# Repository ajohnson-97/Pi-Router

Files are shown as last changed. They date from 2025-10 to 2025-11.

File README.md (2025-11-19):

# Pi-Router

Custom-built dual 2.5Gb ethernet and WIFI 6e router/dns-sinkhole using Raspberry Pi SBCs and a custom ATMEGA328P-PU circuit for a toggle switch controlled password system to display system configuration details on the LCD screens and control two servo motors that lock/unlock the enclosure.<br><br>
## License

- The code in this repository is licensed under the [MIT License](./LICENSE).
- All images, logos, and branding assets are licensed under the [CC BY-NC-ND 4.0 License](https://creativecommons.org/licenses/by-nc-nd/4.0/). <br>
- See [ASSETS_LICENSE.txt](./ASSETS_LICENSE.txt) for details.
<br><br>
pirouter_Logo (Copy).png
<br><br>
<!--
# Licensing
The code in this repository is licensed under the MIT License. <br> 
- Feel free to use the code in your project or modify/redistribute it any way you'd like.<br>

However, all images, branding, and logo assets (found in the /assets directory) may not be used for commercial purposes or in other projects without explicit permission.
-->


<br><br>

<br><br>

<br><br>

<br><br>

<br><br>

<br><br>

<br><br>
Wiring_Diagram_TinkerCAD
<br><br>

<br><br>


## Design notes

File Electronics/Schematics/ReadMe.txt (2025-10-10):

The schematic and wiring diagram feature an Arduino Uno because I designed the prototype using tinkerCAD and it doesn't have an object for the atmega328p-pu chip that I used in the actual project. You can get away with using any Arduino as it uses the same chip, assuming you can accommodate the space and adjust the mounting holes accordingly. If you want to use the atmega chip directly like I did you'll have to research how to do it yourself for the most part, but basically, it's the same connections as the Arduino. You'll need to consult a pinout diagram to make sure you're connecting wires from the digital output pin numbers and not by counting the hardware pins on the chip. For example the first pin on the chip is the reset pin, not digital output pin 1, consult the diagram and you'll understand what I mean. You'll also want to solder a 16Mhz crystal oscillator to the corresponding pins and connect them to ground through 100pF ceramic capacitors. I also added a 10kohm resistor from the reset pin to VCC as a pullup resistor to reset the chip, you can skip this step if you set the pinMode using the built-in pullup resistor in your code. I also put a 100uF polarized capacitor across 5V and ground to smooth out any electrical noise, it's not necessary but recommended.

The schematics might not be fully accurate, they were generated from tinkercad and I changed up the final design a bit in my project. It's more for reference.

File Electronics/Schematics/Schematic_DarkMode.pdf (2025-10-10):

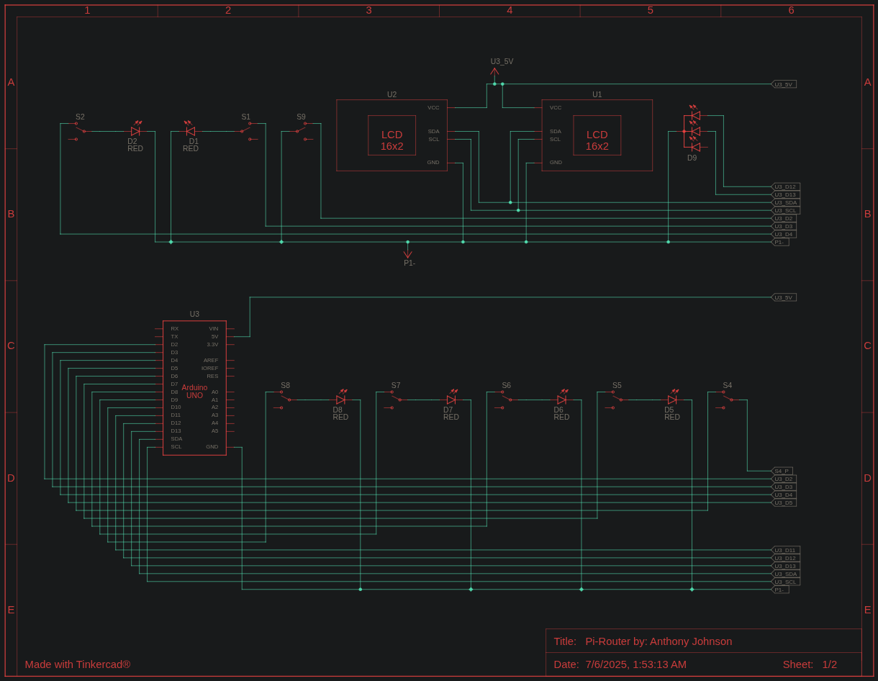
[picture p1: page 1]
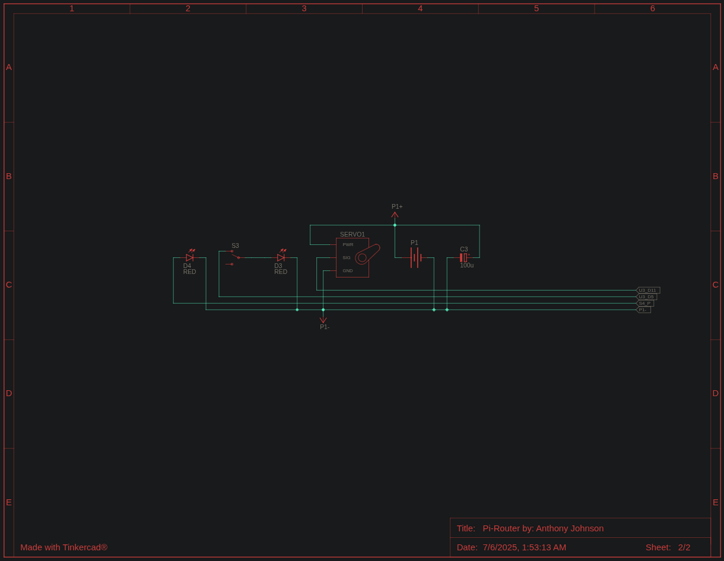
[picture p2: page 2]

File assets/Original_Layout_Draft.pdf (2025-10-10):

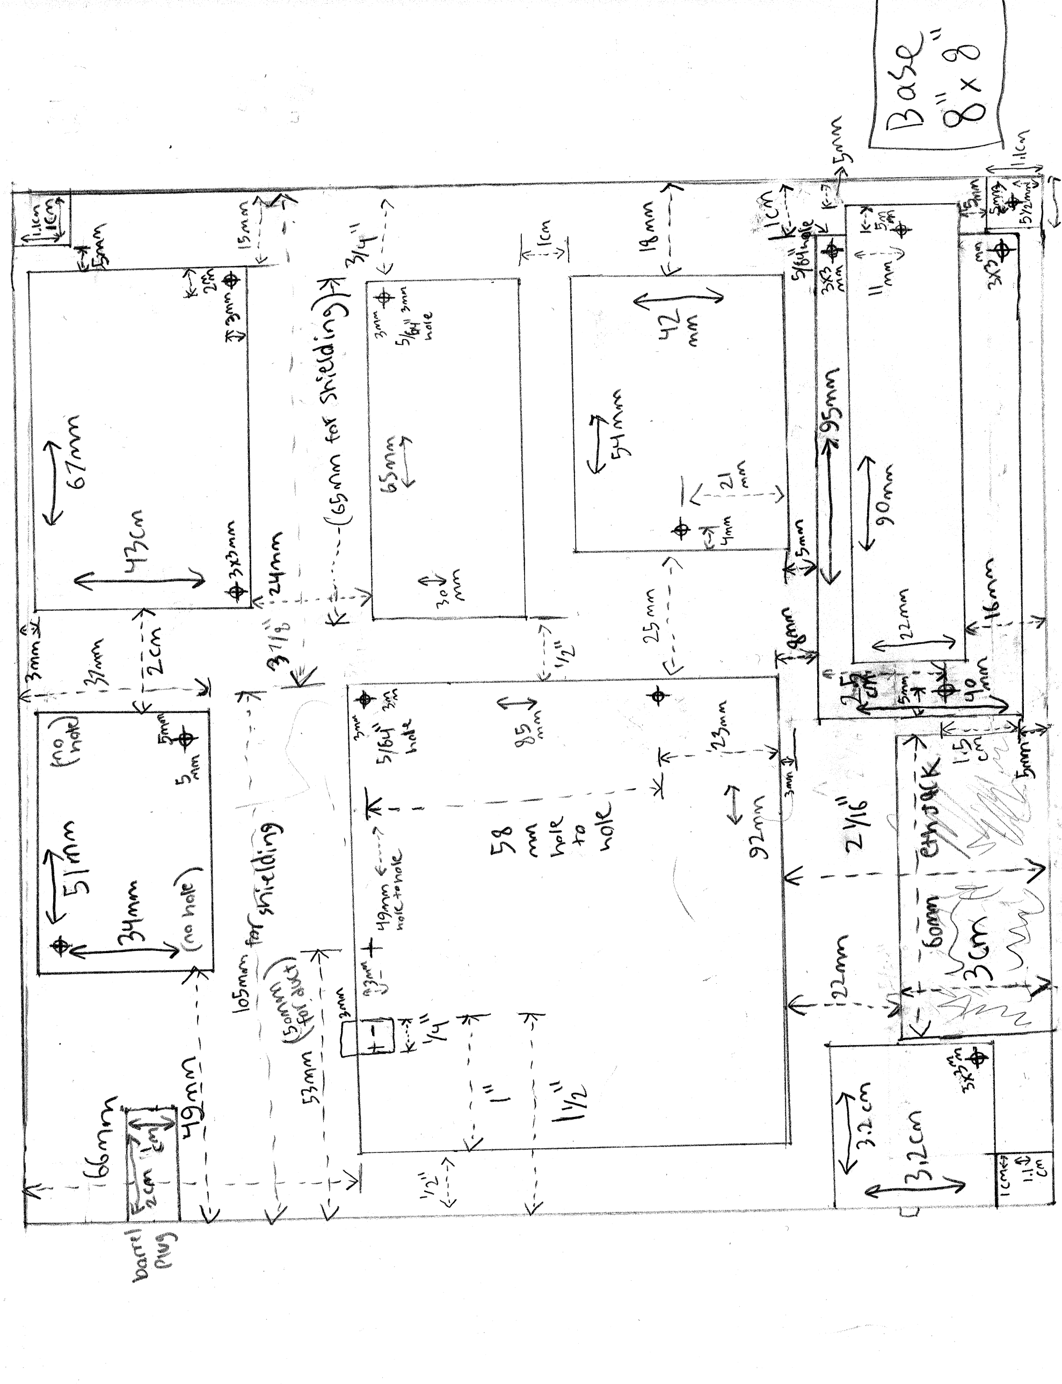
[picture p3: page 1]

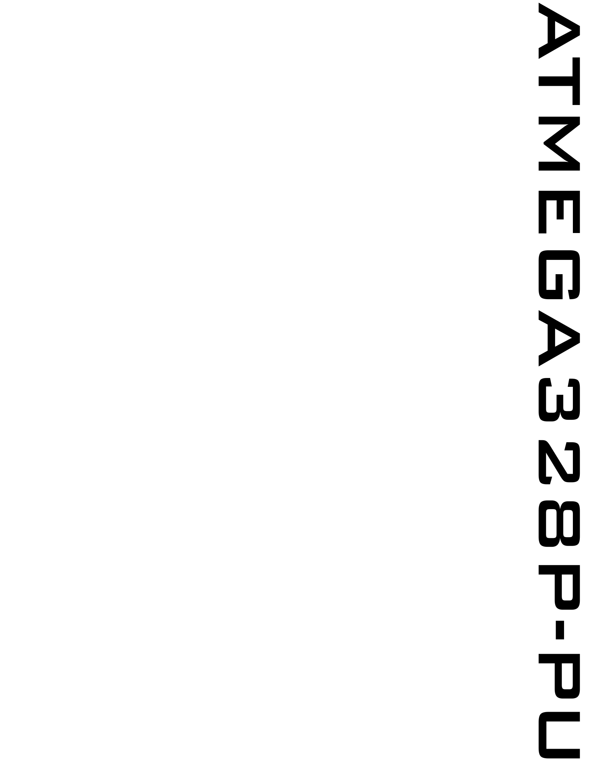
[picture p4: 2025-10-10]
CAD Files/PNGs/atmega328.png

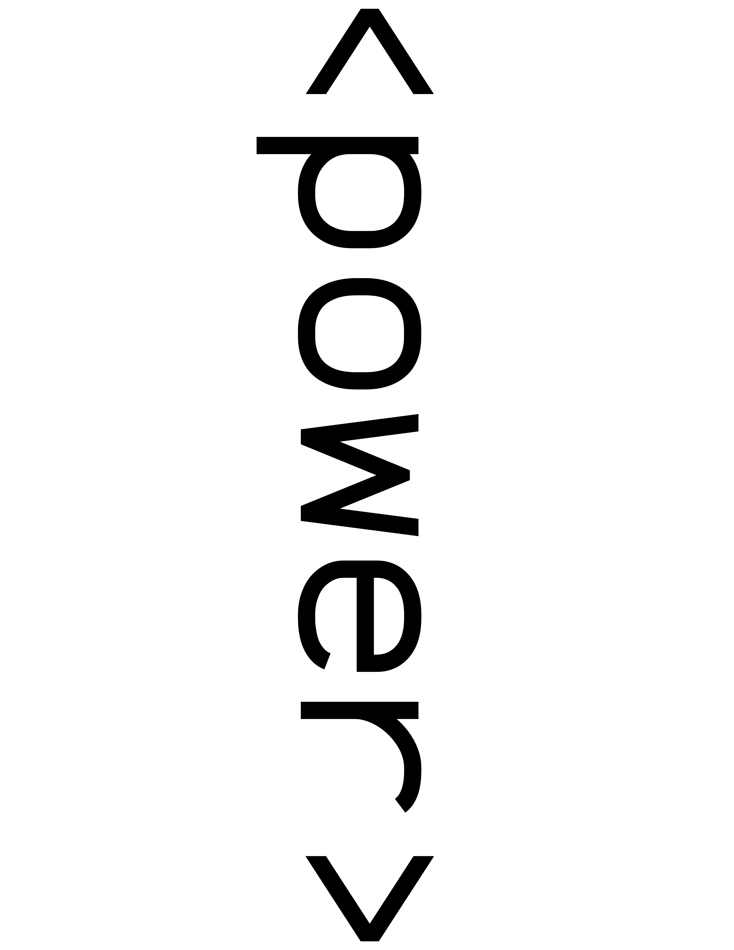
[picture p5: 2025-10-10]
CAD Files/PNGs/power.png

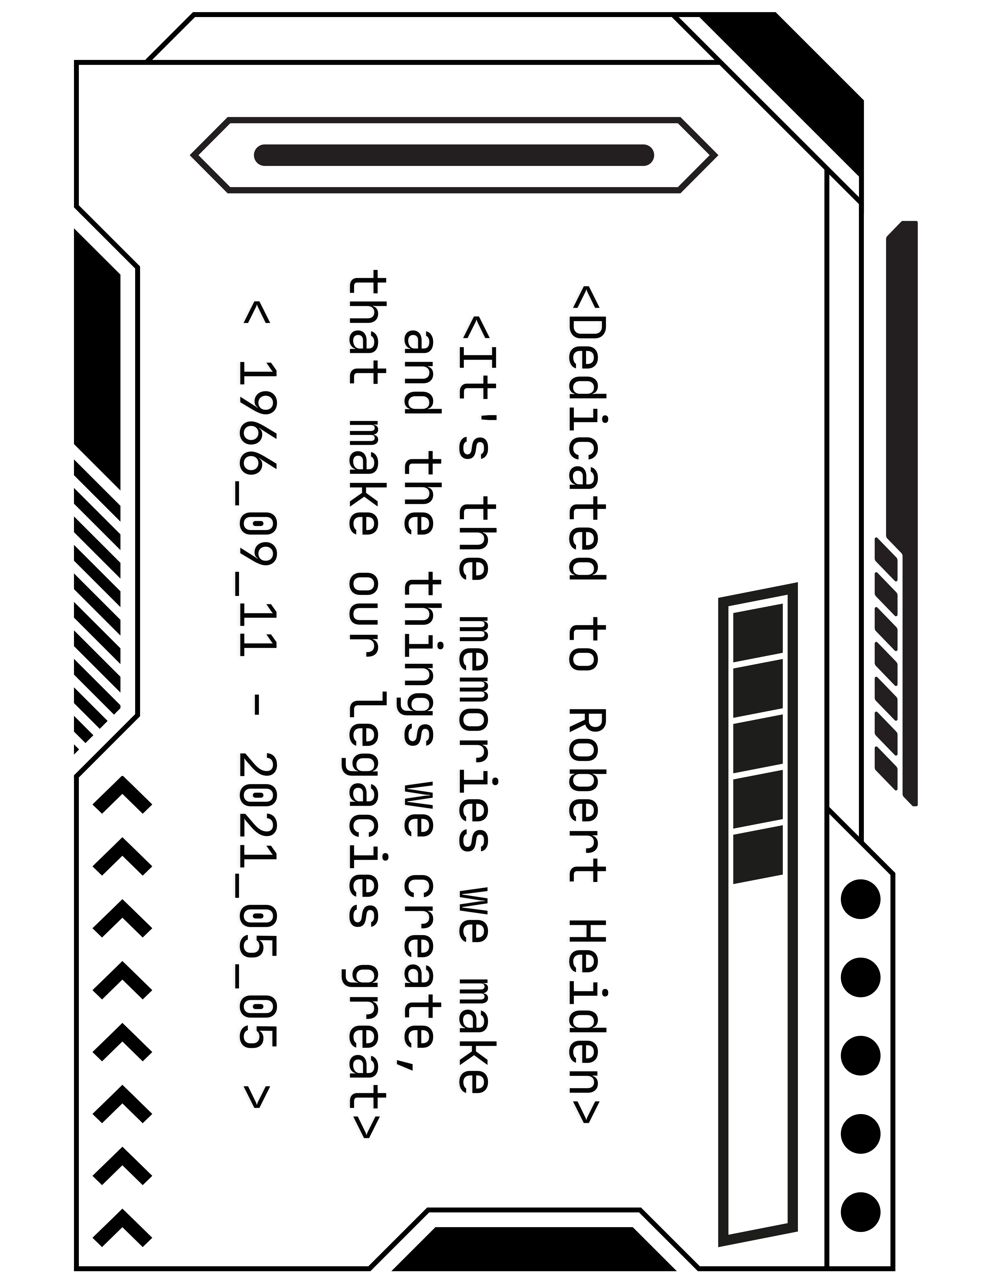
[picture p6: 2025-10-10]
CAD Files/PNGs/dedication.png

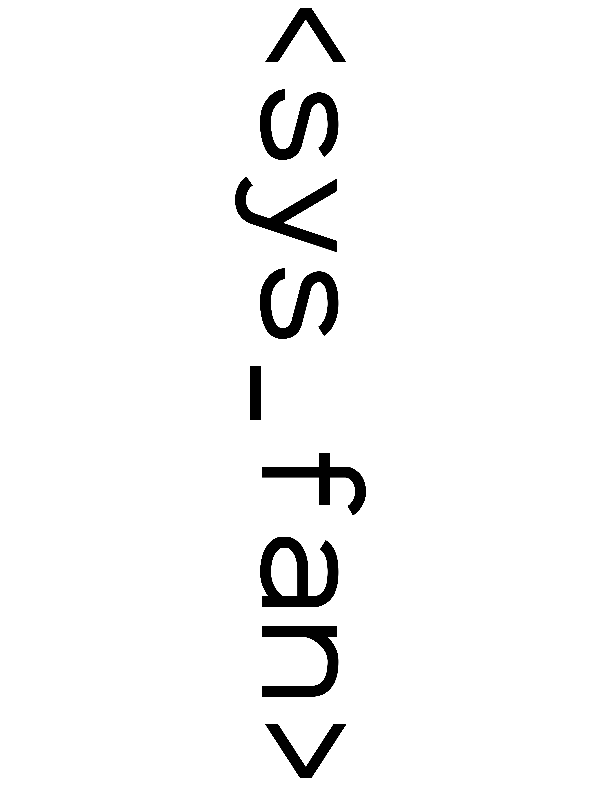
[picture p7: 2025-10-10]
CAD Files/PNGs/sysfan.png

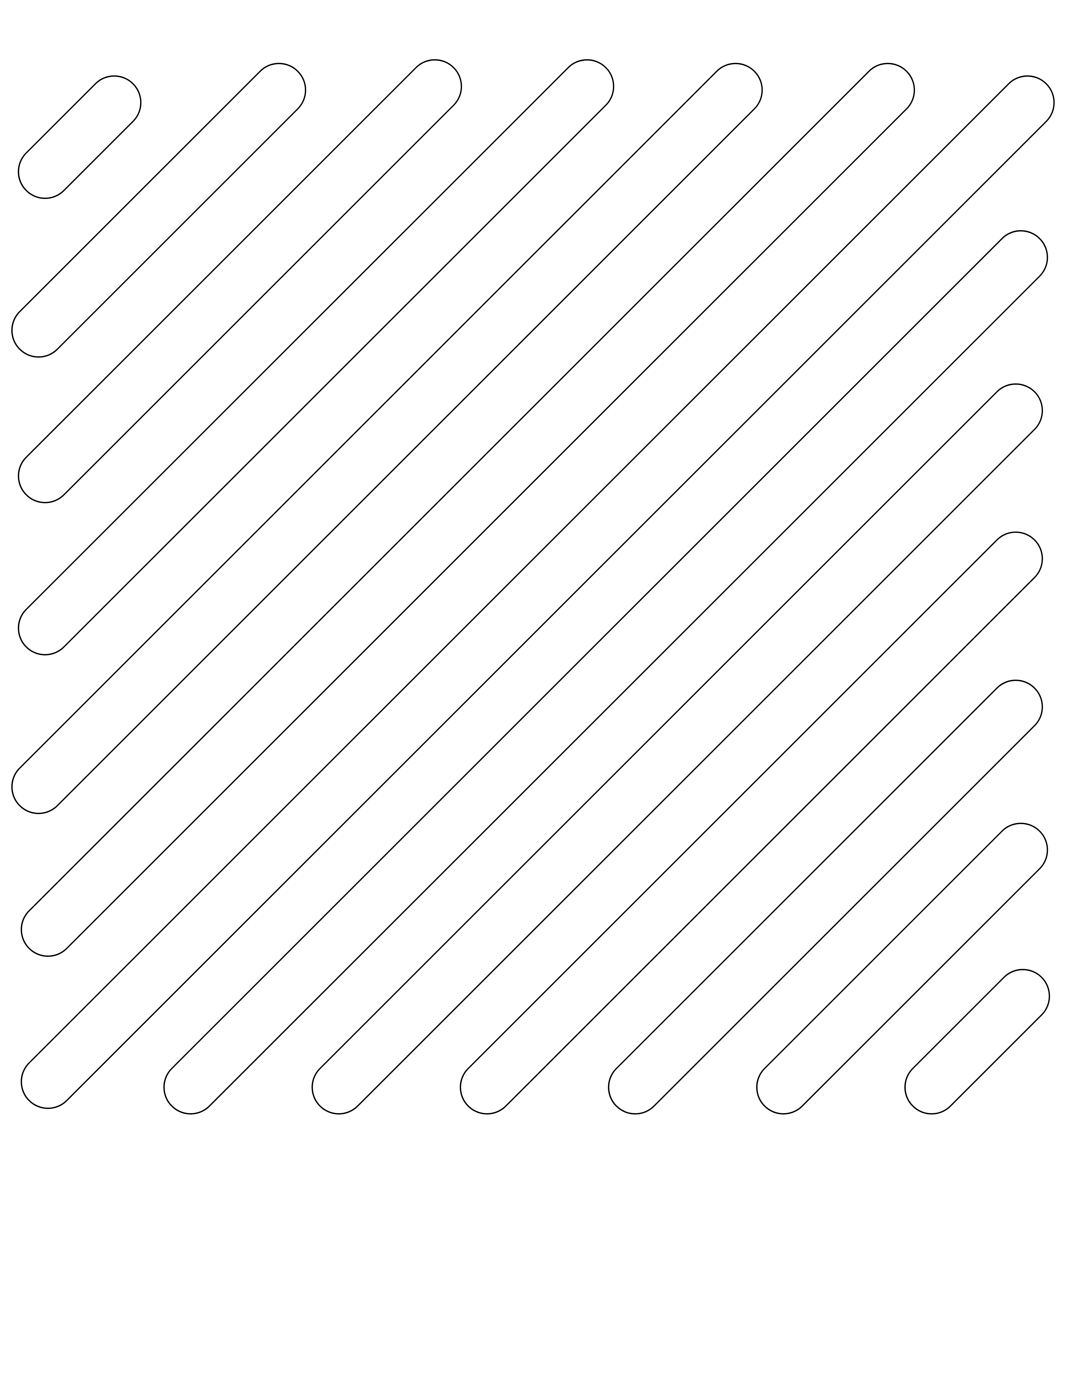
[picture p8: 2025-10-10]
CAD Files/PNGs/ventholes.png

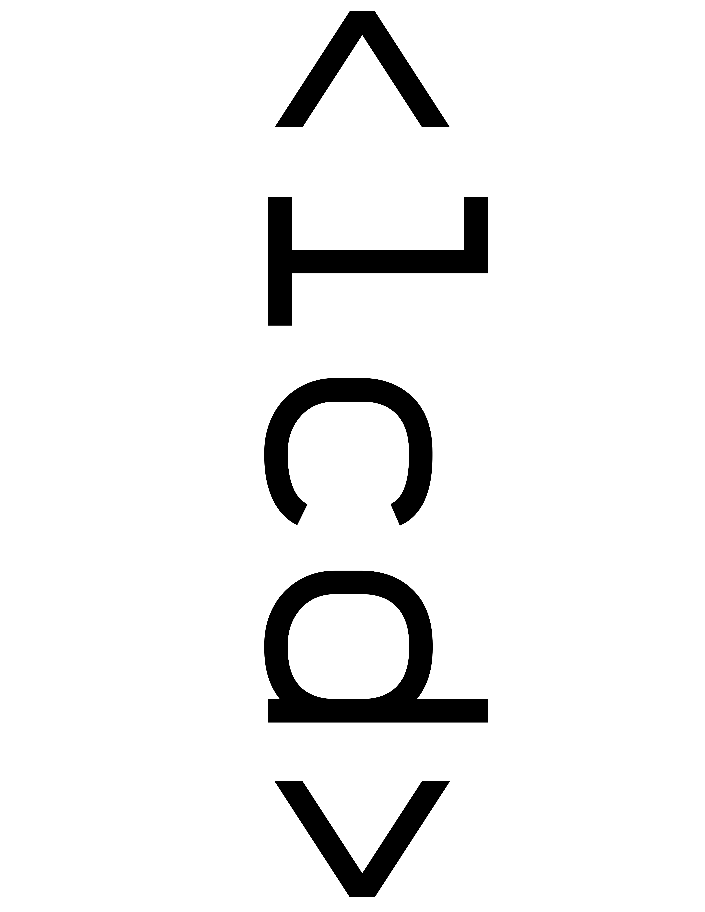
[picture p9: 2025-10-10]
CAD Files/PNGs/lcd.png

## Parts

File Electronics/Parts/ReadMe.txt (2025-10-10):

Excludes things like jumper wires, proto-board, header pins, terminal blocks... Very Basic generated list from tinkerCAD and not a complete list of parts in my final project. Also doesn't include the structure, just for the electrical componants regarding the password system, not the main boards.

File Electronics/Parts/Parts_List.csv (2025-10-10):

Name | Quantity | Component
U1 | 1 | PCF8574-based, 39 (0x27) LCD 16 x 2 (I2C)
U2 | 1 | PCF8574-based, 35 (0x23) LCD 16 x 2 (I2C)
SERVO1 | 1 | Positional Micro Servo
D1, D2, D3, D4, D5, D6, D7, D8 | 8 | Red LED
D9 | 1 | RCBG LED RGB
S1, S2, S3, S4, S5, S6, S7, S8, S9 | 9 | Slideswitch
C3 | 1 | 100 uF, 25 V Polarized Capacitor
U3 | 1 | Arduino Uno R3
P1 | 1 | 5 , 1 Power Supply

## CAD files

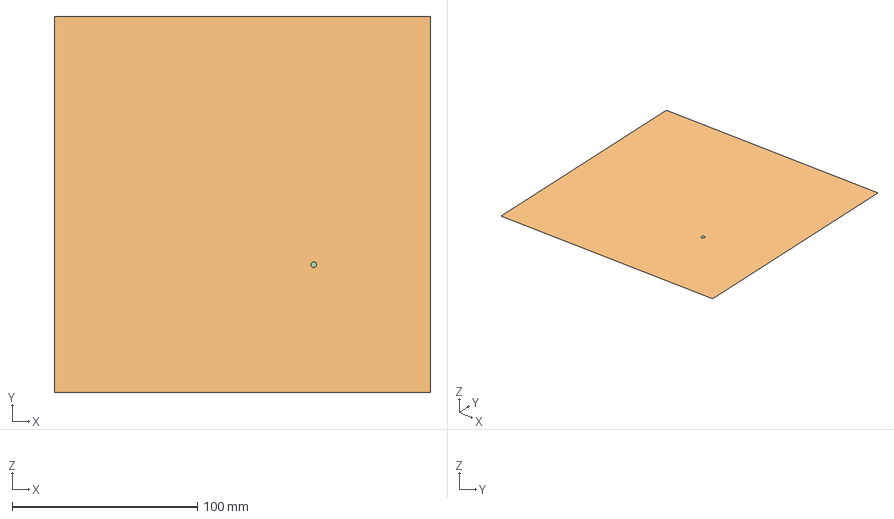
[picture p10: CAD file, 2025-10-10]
CAD Files/piRouterBase_Final.FCStd
203.0 x 203.0 x 0 mm
Standoff_Mount-Bottom_Left-Drill_Hole
Base
Circle033
Circle034
Circle035
Circle036

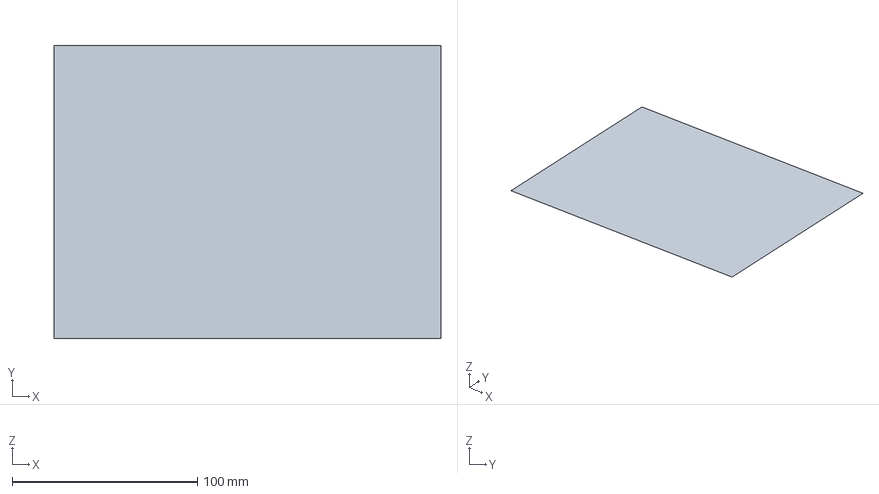
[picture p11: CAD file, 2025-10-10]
CAD Files/piRouterFront_FinalShorter.FCStd
209.0 x 158.4 x 0 mm

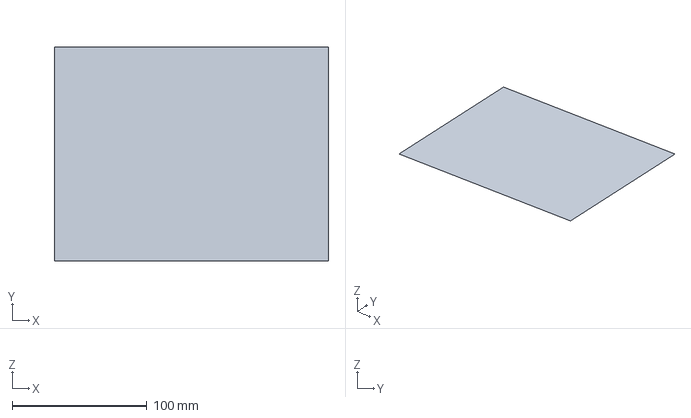
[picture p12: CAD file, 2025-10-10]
CAD Files/piRouterRightSide_Final.FCStd
203.0 x 158.4 x 0 mm

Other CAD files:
CAD Files/piRouterLeftSide_Final.FCStd
CAD Files/piRouterTop_Final.FCStd
CAD Files/piRouterBack_FinalShorter.FCStd

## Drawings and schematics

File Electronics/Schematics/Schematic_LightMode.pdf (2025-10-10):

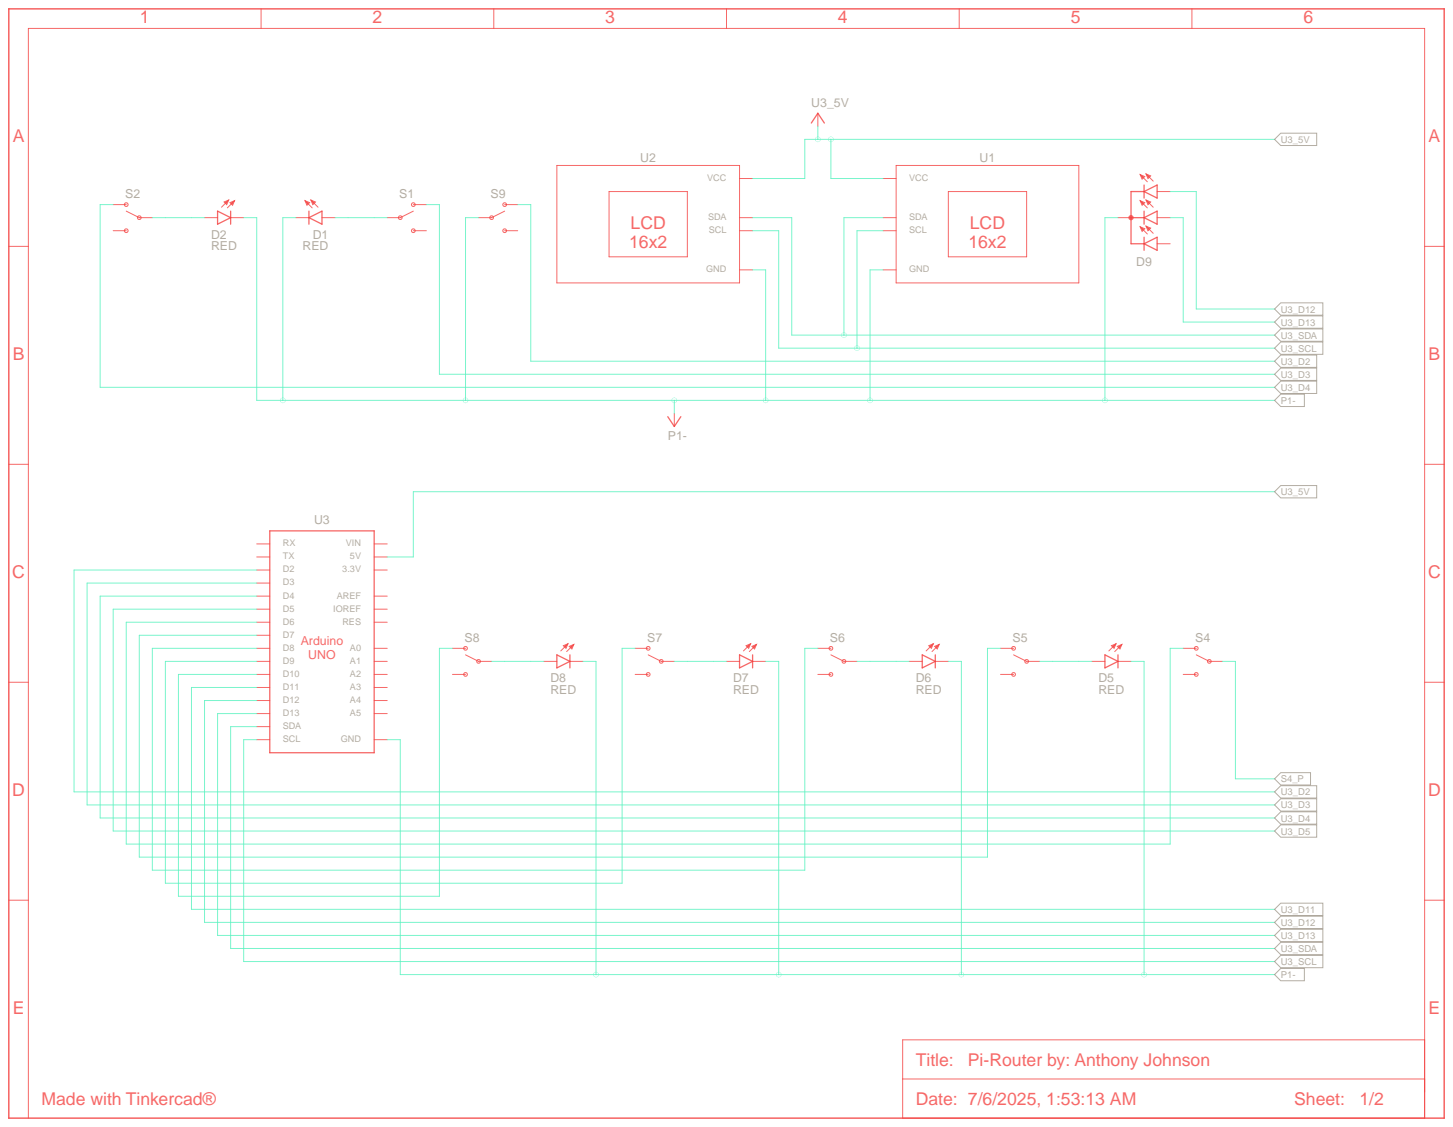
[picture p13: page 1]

Title: Pi-Router by: Anthony Johnson

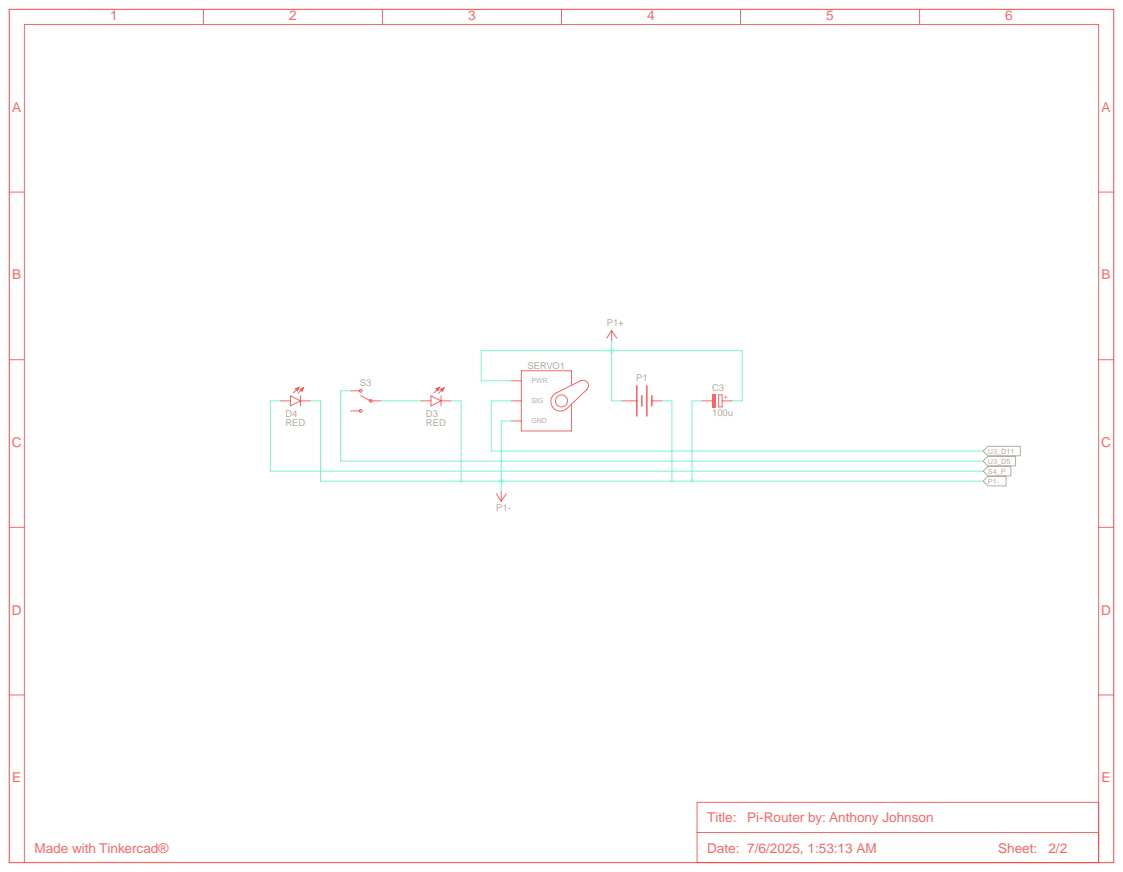
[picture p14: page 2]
Date: 7/6/2025, 1:53:13 AM; Sheet: 2/2; D4 RED; D3 RED; PWR; SIG; GND; SERVO1

Title: Pi-Router by: Anthony Johnson

Made with Tinkercad®

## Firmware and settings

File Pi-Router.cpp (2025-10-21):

// Pi-Router Display/Password System
// https://github.com/ajohnson-97/Pi-Router
// Written By: Anthony Johnson

// Upload while bypassing the boot-loader to speed up onset after powering on the device.
#include <Servo.h>
#include <LiquidCrystal_I2C.h>

// Initialize the LCD displays using the hardware address of the displays (in my case thats 0x23/27) check for your devices and adjust accordingly.
LiquidCrystal_I2C lcd1(0x27, 16, 2);
LiquidCrystal_I2C lcd2(0x23, 16, 2);

Servo myServos;
int servoLocked = 90;
int servoUnLocked = 0;

// Set a variable for the pin connected to the key-switch that will act as the master switch (must be digital pin 1 or 2 on an arduino if using it as a hardware interrupt).
int keySwitch = 2;
int ledPins[] = {3, 4, 5, 6, 7, 8, 9, 10}; // Assigned pin numbers to variables, stored in a list. 
int correctPattern[] = {HIGH, HIGH, LOW, LOW, HIGH, HIGH, LOW, HIGH}; // Reference pattern to compare the list of input pins to determine if that password is correct.
int redPinLED = 12;
int greenPinLED = 13;

// Create the custom characters for the LCD display by setting the bytes manually.
byte smallxChar[8] = {0b00000,0b00000,0b00000,0b10001,0b01010,0b00100,0b01010,0b10001};
byte bigxChar1[8] = {0b01000,0b00100,0b00010,0b00001,0b00001,0b00010,0b00100,0b01000};
byte bigxChar2[8] = {0b00010,0b00100,0b01000,0b10000,0b10000,0b01000,0b00100,0b00010};
byte leftDash[8] = {0b00000,0b00000,0b00000,0b00111,0b00111,0b00000,0b00000,0b00000};
byte rightDash[8] = {0b00000,0b00000,0b00000,0b11100,0b11100,0b00000,0b00000,0b00000};

void setup() 
{
  lcd1.init();
  lcd2.init();
  lcd1.backlight();
  lcd2.backlight();
  lcd1.clear();
  lcd2.clear();

  // Set the LED pins as digital inputs, using the onboard pull-up resistors to pull the values up to 5V and out of a floating state.
  for (int i = 0; i < 8; i++) {
    pinMode(ledPins[i], INPUT_PULLUP);
  }
  pinMode(keySwitch, INPUT_PULLUP);
  pinMode(redPinLED, OUTPUT);
  pinMode(greenPinLED, OUTPUT);

  myServos.attach(11); // Must attach the servo data pin to a PWM capable pin.
  myServos.write(servoLocked);

  // Index the custom LCD characters
  lcd1.createChar(0, smallxChar);
  lcd1.createChar(1, bigxChar1);
  lcd1.createChar(2, bigxChar2);
  lcd1.createChar(3, leftDash);
  lcd1.createChar(4, rightDash);
}

void loop() 
{
  myServos.write(servoLocked);
  digitalWrite(greenPinLED, LOW);
  digitalWrite(redPinLED, LOW);
  welcomeMessage();

  if (digitalRead(keySwitch) == LOW) { // If the key-switch is engaged (value will register as low when engaged because the pull-up resistor keeps the pin at 5V when the circuit is open).
    if (patternCheck()) { // If the password is incorrect.
      myServos.write(servoUnLocked);
      successMessage();
      digitalWrite(greenPinLED, HIGH);
      digitalWrite(redPinLED, LOW);
    } else { // If the password is incorrect.
      myServos.write(servoLocked);
      failureMessage();
      digitalWrite(greenPinLED, LOW);
      redLEDFlash();
    }
  } 
}

bool patternCheck() 
{
  for (int i = 0; i < 8; i++) {
    int pinState = digitalRead(ledPins[i]);
    int referencePattern = correctPattern[i];
    if (pinState != referencePattern) {
      return false;
    }
  }
  return true;
}

void welcomeMessage()
{
  lcd1.setCursor(0,0);
  lcd1.write((byte)0);
  lcd1.setCursor(1,0);
  lcd1.write((byte)1);
  lcd1.setCursor(2,0);
  lcd1.write((byte)2);
  
  lcd1.setCursor(3,0);
  lcd1.print("PI");
  
  lcd1.setCursor(5,0);
  lcd1.write((byte)3);
  lcd1.setCursor(6,0);
  lcd1.write((byte)4);
  
  lcd1.setCursor(7,0);
  lcd1.print("ROUTER");
  
  lcd1.setCursor(13,0);
  lcd1.write((byte)1);
  lcd1.setCursor(14,0);
  lcd1.write((byte)2);
  lcd1.setCursor(15,0);
  lcd1.write((byte)0);
  
  lcd1.setCursor(0,1);
  lcd1.print("2.5Gb & WIFI 6e ");
  lcd2.setCursor(0,0);
  lcd2.print("    Made by:    ");
  lcd2.setCursor(0,1);
  lcd2.print("Anthony Johnson ");
}

void successMessage() 
{
  lcd1.setCursor(0, 0);
  lcd1.print("Access Granted! ");
  lcd1.setCursor(0,1);
  lcd1.print("WPA2: Password! ");
  lcd2.setCursor(0,0);
  lcd2.print("SSH: 10.7.7.1   ");
  lcd2.setCursor(0,1);
  lcd2.print("DNS: 10.7.7.2   ");
}

void failureMessage() 
{
  lcd1.setCursor(0, 0);
  lcd1.print("Error Wrong Code");
  lcd1.setCursor(0, 1);
  lcd1.print("  Try Again...  ");
  lcd2.setCursor(0,0);
  lcd2.print("Or try using a..");
  lcd2.setCursor(0,1);
  lcd2.print("    Hammer?     ");
}

void redLEDFlash() 
{
  analogWrite(redPinLED, 255);
  delay(500);
  analogWrite(redPinLED, 0);
  delay(500);
}
